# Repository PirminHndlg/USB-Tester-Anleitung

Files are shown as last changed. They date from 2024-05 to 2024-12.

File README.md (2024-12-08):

<h1>Anleitung zum USB Tester Löt Kit</h1>

<div class="img-container">
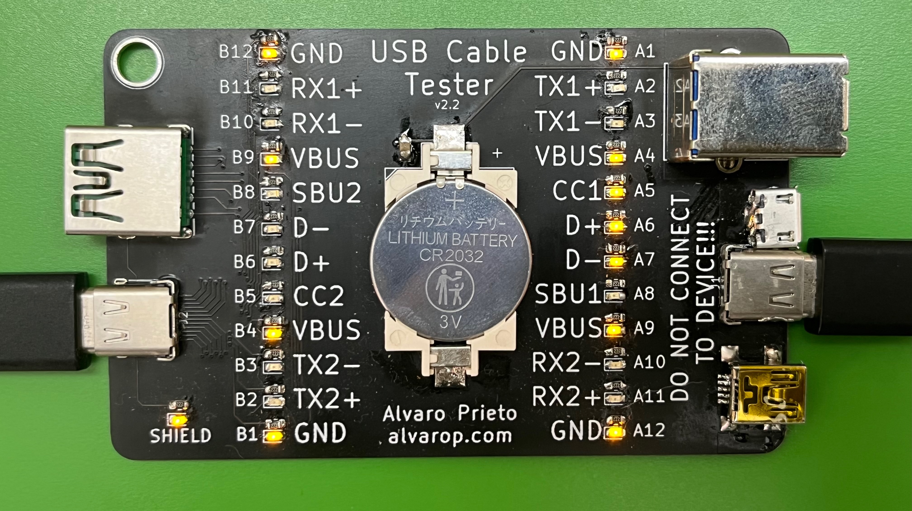
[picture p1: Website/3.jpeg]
    
</div>

<h4>Enthaltene Komponenten</h4>
<ul>
    <li>1x pcb</li>
    <li>2x USB Typ-C Buchse (teilweise schon an pcb angelötet)</li>
    <li>1x USB Typ-A 3.0 Buchse</li>
    <li>1x Micro USB Typ-B Buchse</li>
    <li>1x Mini USB Typ-B Buchse</li>
    <li>1x USB Typ-B 3.0 Buchse</li>
    <li>1x Batterie Halterung</li>
    <li>30x Widerstand 2.2kΩ (25 + 5 Reserve)</li>
    <li>30x LEDs gelb (25 + 5 Reserve)</li>
    <li>1x Kondensator 10μF</li>
</ul>

<div class="img-container">
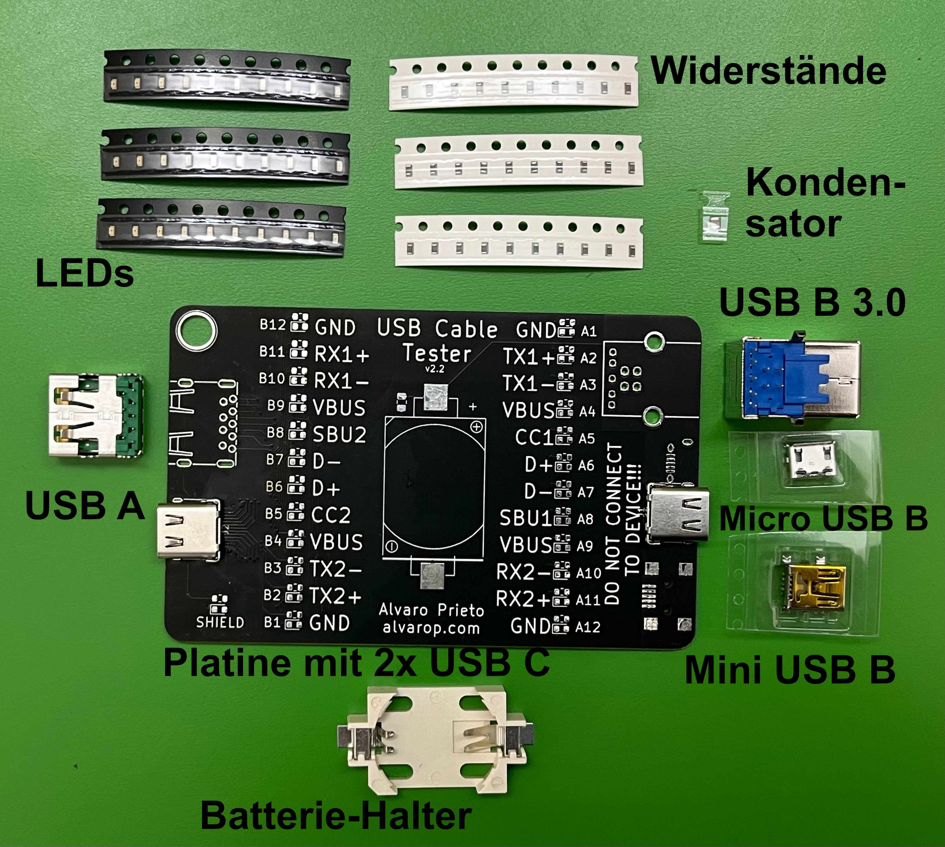
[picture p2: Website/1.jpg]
Komponentenübersicht
    
</div>

<p style="background-color: green; padding: 10px"><strong>Hinweis:</strong> Bei der USB-C Buchse auf der rechten Seite
    kann es sein, dass sich einige Pins untereinander brücken. Das ist kein Problem! Die Kontakte auf dem pcb sind
    sowieso mit einer VCC-Plane verbunden. Auf der linken Seite darf es aber nicht sein!</p>

<h4>Anleitung</h4>
<ol>
    <li>
        Löte die Widerstände und die LEDs auf die Platine, die oberen Kontakte sind für die Widerstände und die
        unteren für die LEDs
        <p style="background-color: red; padding: 10px"><strong>Wichtig:</strong> die LEDs haben eine Ausrichtung!</p>
        <div class="Website/img-container">
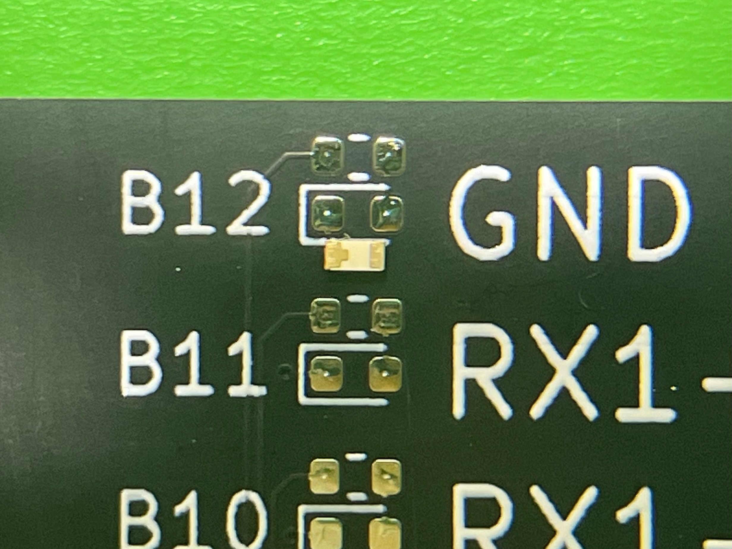
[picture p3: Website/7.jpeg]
Close-Up auf LED-Rückseite
            
        </div>
        Auf der Rückseite der LED sieht man eine Markierung für die Kontakte. Der Kontakt mit dem Kreuz ist der Minuspol
        und muss an den linken Kontakt der Platine mit der vollständigen Umrandung gelötet werden.
        <div class="Website/img-container">
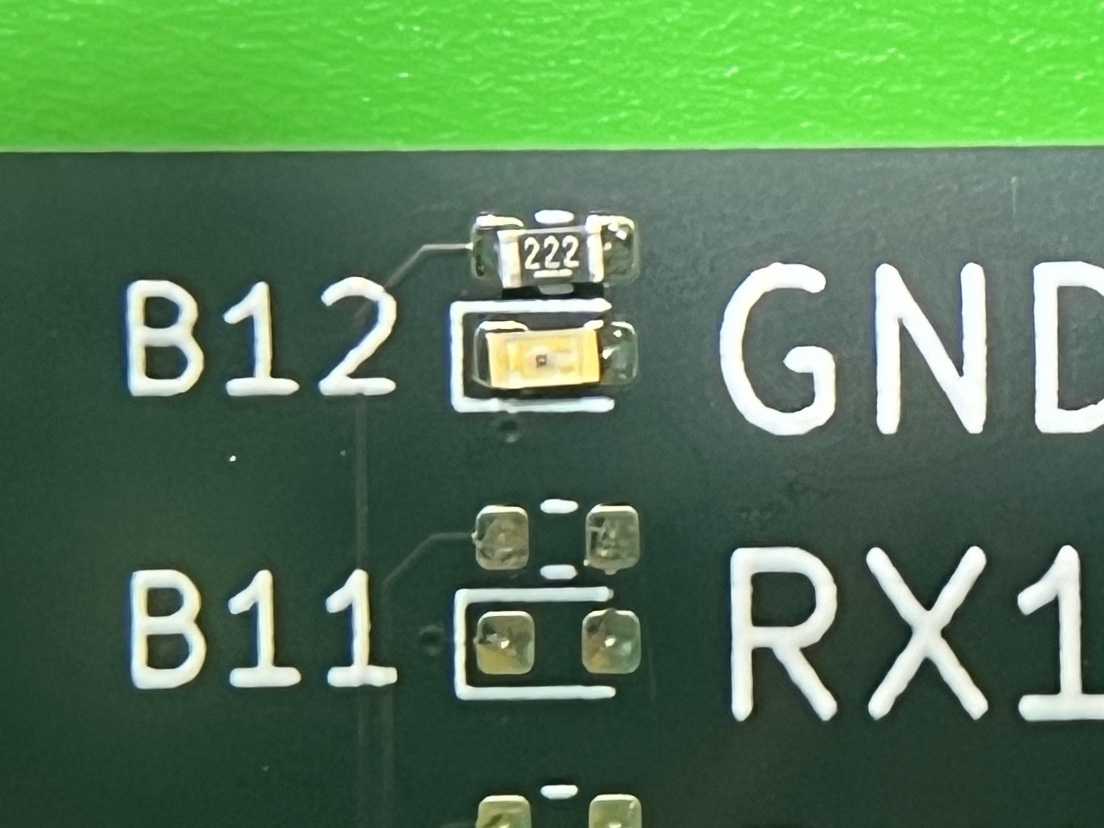
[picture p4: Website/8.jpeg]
Close-Up auf LED und Widerstand
            
        </div>
        Auf der Vorderseite ist die Unterscheidung der beiden Kontakte der LEDs leider nur schwer zu erkennen, aber der
        Pluspol hat zwei kleine Streifen und der Minuspol nur einen.
        <br><br>
        12 LEDs + Widerstände sind für die linke Seite der Platine und 12 für die rechte Seite bestimmt. Das letze Paar
        kommt unten in die linke Ecke der Platine bei der Aufschrift "SHIELD".
    </li>
    <li>
        Löte die Buchsen auf die Platine. Anordnung siehe Bild. Für die Stecker auf der rechten Seite spielt es
        keine Rolle, ob einzelne Kontakte sich untereinander berühren und einen Kurzschluss bilden.
        <div class="img-container">
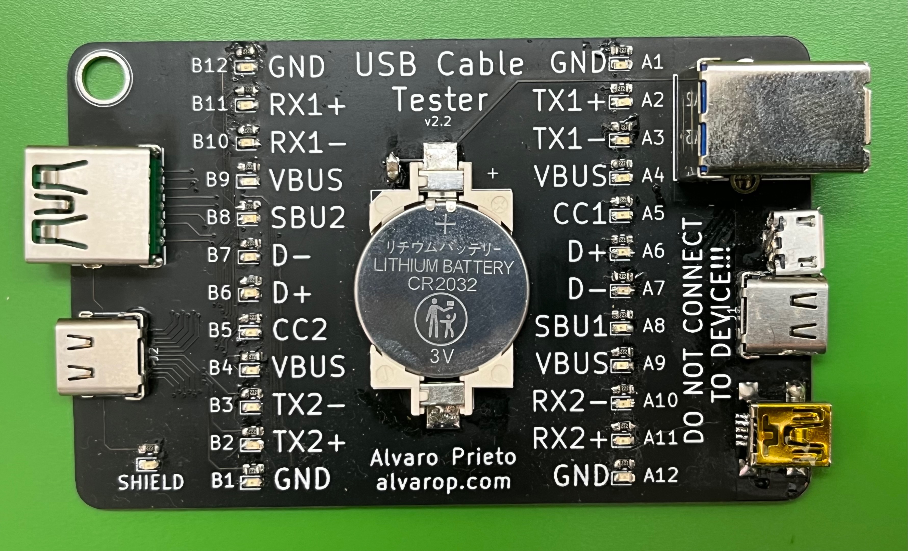
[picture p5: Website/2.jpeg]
Bild von Vorderseite
            
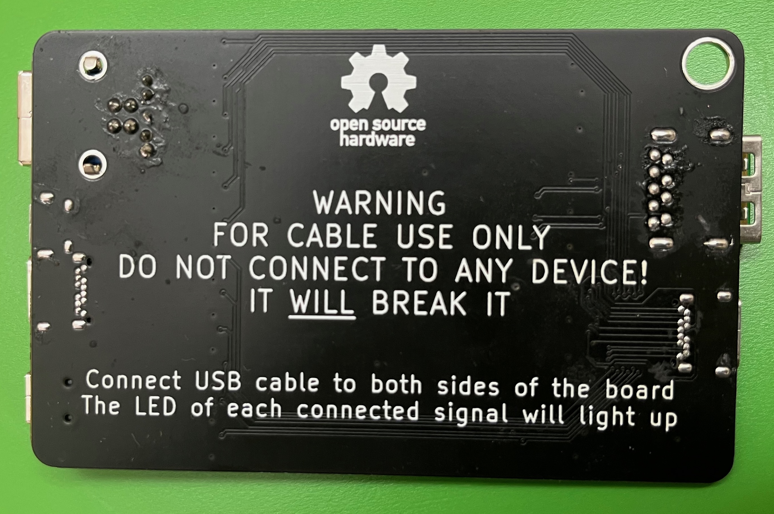
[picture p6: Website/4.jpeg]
Bild von Rückseite
            
        </div>
        Falls die USB-C Buchsen noch nicht angelötet sind, ist das der schwierigste Teil. Ich war am erfolgreichsten,
        indem ich die mit Reflow-Löten angelötet habe.
        <p style="background-color: orange; padding: 10px"><strong>Hinweis:</strong> Bei der Micro-USB-B-Buche habe ich einen kleinen Fehler beim pcb gemacht. Diese muss sich das eine Bein mit einer USB-C-Buchse teilen. Gequetscht sollte aber alles nebeneinander passen.</p>
    </li>
    <li>
        Löte den Kondensator an die richtige Stelle neben dem Pluspol der Batterie. Die Ausrichtung spielt keine Rolle.
        <div class="img-container">
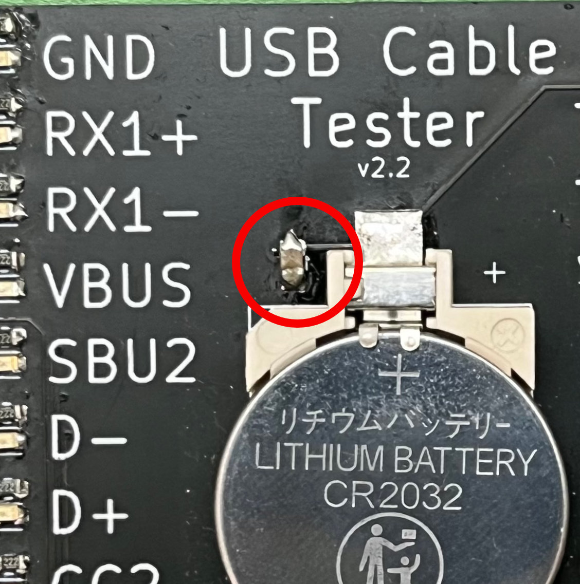
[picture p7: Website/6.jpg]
Close-Up auf Kondensator
            
        </div>
    </li>
    <li>
        Löte die Batterie-Halterung an. Achte auf die richtige Polung! Es gibt eine kleine Markierung an der Ecke der
        Halterung für den Plus- und Minuspol.
    </li>
    <li>
        Und fertig ist dein USB Tester! Viel Spass beim Testen von USB-Kabeln!
    </li>
</ol>

<h3 style="background-color: red; text-align: center; padding: 10px; border-radius: 10px">Wie es auch überall steht, ist es wichtig, dass man
    den Tester <strong>nicht</strong> an ein Gerät anschließt,
    sondern nur Kabel!</h3>

<div class="img-container">
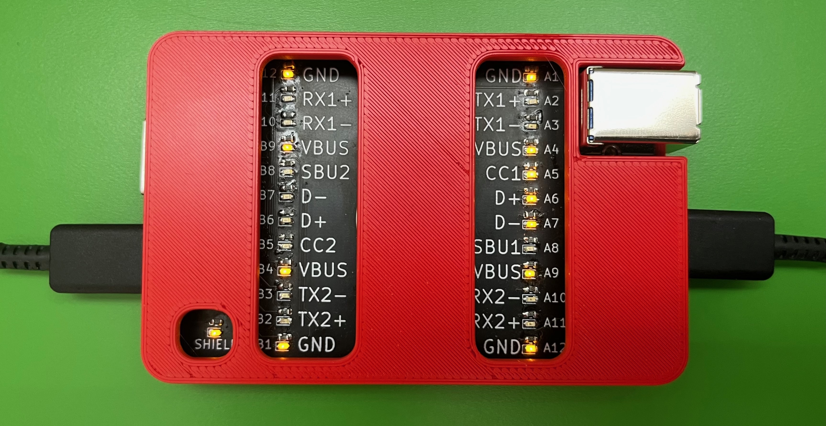
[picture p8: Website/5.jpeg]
Bild von fertigem Tester
    
</div>

<h4>Weitere Links</h4>

<p><a href="https://github.com/PirminHndlg/USB-Tester-Anleitung/tree/main/Case">Hier</a> gibt eine 3D-Druck-Vorlage für
    ein kleines, einfaches Case.</p>

<p><a href="https://github.com/PirminHndlg/USB-Tester-Anleitung/tree/main/pcb">Hier</a> kann man das KiCad-Projekt zum
    pcb finden. Ich habe das <a href="https://github.com/alvarop/usb_c_cable_tester">Original von alvarop</a> etwas
    angepasst, da einzelne Teile nicht mehr verfügbar waren. Eine aktuelle Liste gibt es <a
            href="https://github.com/PirminHndlg/USB-Tester-Anleitung/blob/main/pcb/LCSC%20Exported%20May%2030%202024.csv">hier</a>
</p>

<h4>Erklärung zur Pin-Belegung</h4>

<div class="table-container">
    <table>
        <tr>
            <th>Charge only</th>
            <td>GND</td>
            <td>VBUS</td>
        </tr>
        <tr>
            <th>USB 2.0</th>
            <td>GND</td>
            <td>VBUS</td>
            <td>D-</td>
            <td>D+</td>
        </tr>
        <tr>
            <th>USB 3.0</th>
            <td>GND</td>
            <td>VBUS</td>
            <td>D-</td>
            <td>D+</td>
            <td>RX-</td>
            <td>RX+</td>
            <td>TX-</td>
            <td>TX+</td>
        </tr>
    </table>
</div>
<p>Bei USB-C als Host (Buchse auf linker Seite) und Client (Buchse auf rechter Seite) leuchten beide Seiten, da dann
    sowohl die A als auch die B Pins verbunden sind. Außerdem sollte mind. ein CC-Pin verbunden sein</p>

<div class="img-container">
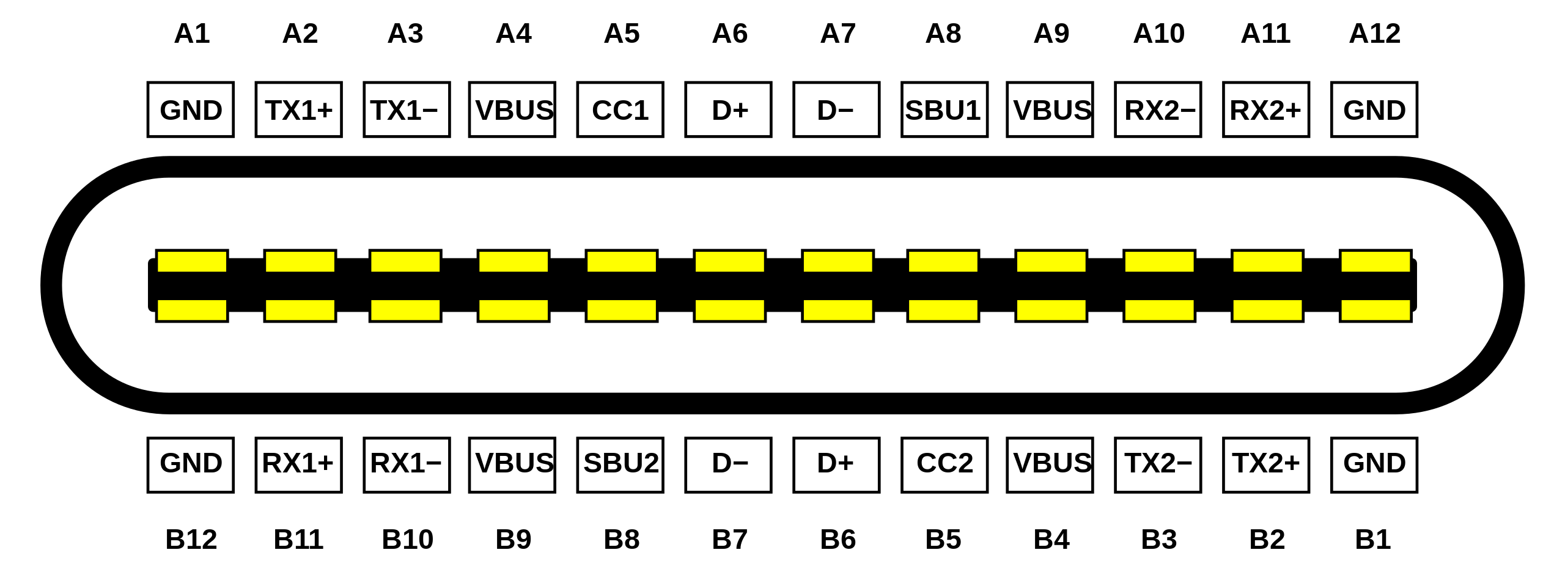
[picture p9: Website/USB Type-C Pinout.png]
Pinbelegung von USB C
    
</div>

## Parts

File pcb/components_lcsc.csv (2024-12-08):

LCSC Part Number | Manufacture Part Number | Manufacturer | Customer NO. | Package | Description | RoHS | Order Qty. | Min\Mult Order Qty. | Unit Price($) | Order Price($)
C72038 | 19-213/Y2C-CQ2R2L/3T(CY) | Everlight Elec |  | 0603 | 20mA Colorless Transparent Lens -40℃~+85℃ 585.5nm~591.5nm Yellow 120° 60mW 0603 LED Indication - Discrete ROHS | YES | 1500 | 30\30 | 0.0147 | 22.05
C70377 | CR2032-BS-6-1 | Q&J |  | SMD | Battery holder CR2032 SMD Button And Strip Battery Connector ROHS | YES | 50 | 5\5 | 0.125 | 6.25
C381137 | U231-091N-3GRC10 | XKB Connection |  | Plugin | 3A 1 9P Mother -40℃~+85℃ Type-A Plugin USB Connectors ROHS | YES | 50 | 1\1 | 0.3194 | 15.97
C2681563 | MINI 5PTP | SHOU HAN |  | SMD | 1A 1 Horizontal attachment 5P Mother -30℃~+80℃ SMD USB Connectors ROHS | YES | 50 | 10\10 | 0.0576 | 2.88
C2895032 | USB-306BWD-ARW | XUNPU |  | Plugin | USB 3.0 1.8A 1 Bend-in 9P Mother -55℃~+85℃ Type-B Plugin USB Connectors ROHS | YES | 50 | 1\1 | 0.3618 | 18.09
C15850 | CL21A106KAYNNNE | Samsung Electro-Mechanics |  | 0805 | 25V 10uF X5R ±10% 0805 Multilayer Ceramic Capacitors MLCC - SMD/SMT ROHS | YES | 50 | 50\50 | 0.0092 | 0.46
C4190 | 0603WAF2201T5E | UNI-ROYAL(Uniroyal Elec) |  | 0603 | 100mW Thick Film Resistors 75V ±100ppm/℃ ±1% 2.2kΩ 0603 Chip Resistor - Surface Mount ROHS | YES | 1500 | 100\100 | 0.0007 | 1.05
C456013 | TYPE-C 24P QCHT | SHOU HAN |  | SMD | USB 3.1 3A 1 Horizontal attachment 24P Mother -40℃~+85℃ Type-C SMD USB Connectors ROHS | YES | 100 | 1\1 | 0.2745 | 27.45
C10418 | 920-E52A2021S10100 | Jing Extension of the Electronic Co. |  | SMD | 1A USB 2.0 1 5P Mother Micro-B SMD USB Connectors ROHS | YES | 50 | 5\5 | 0.0517 | 2.59

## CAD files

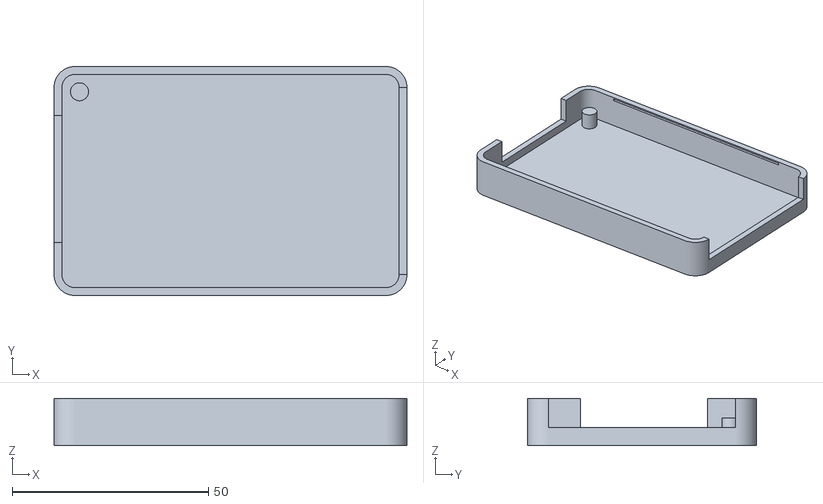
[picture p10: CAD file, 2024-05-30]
Case/USB C Cable Tester Parts Body.stl
90.0 x 58.4 x 12.0

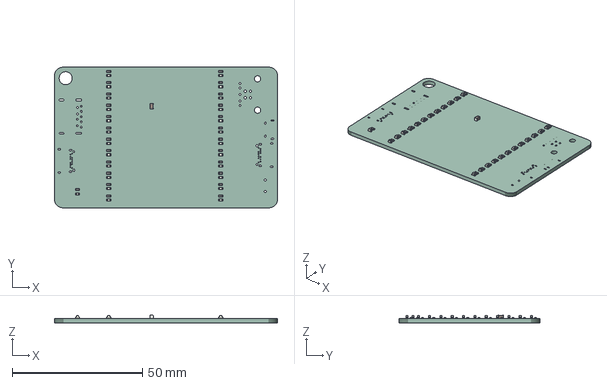
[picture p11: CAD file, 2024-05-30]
pcb/kicad/usb_c_cable_tester.step
85.6 x 54.0 x 2.88 mm
usb_c_cable_tester PCB

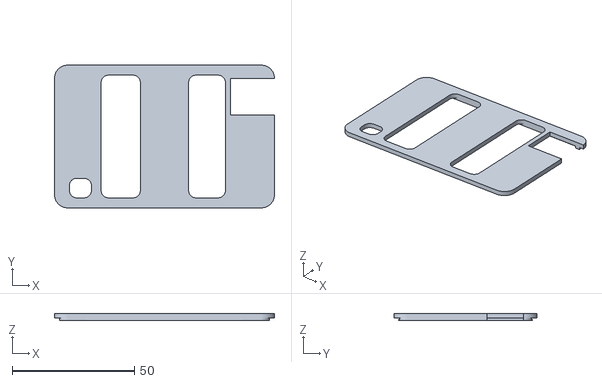
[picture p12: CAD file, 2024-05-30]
Case/USB C Cable Tester Parts Lid.stl
90.0 x 58.4 x 3.00

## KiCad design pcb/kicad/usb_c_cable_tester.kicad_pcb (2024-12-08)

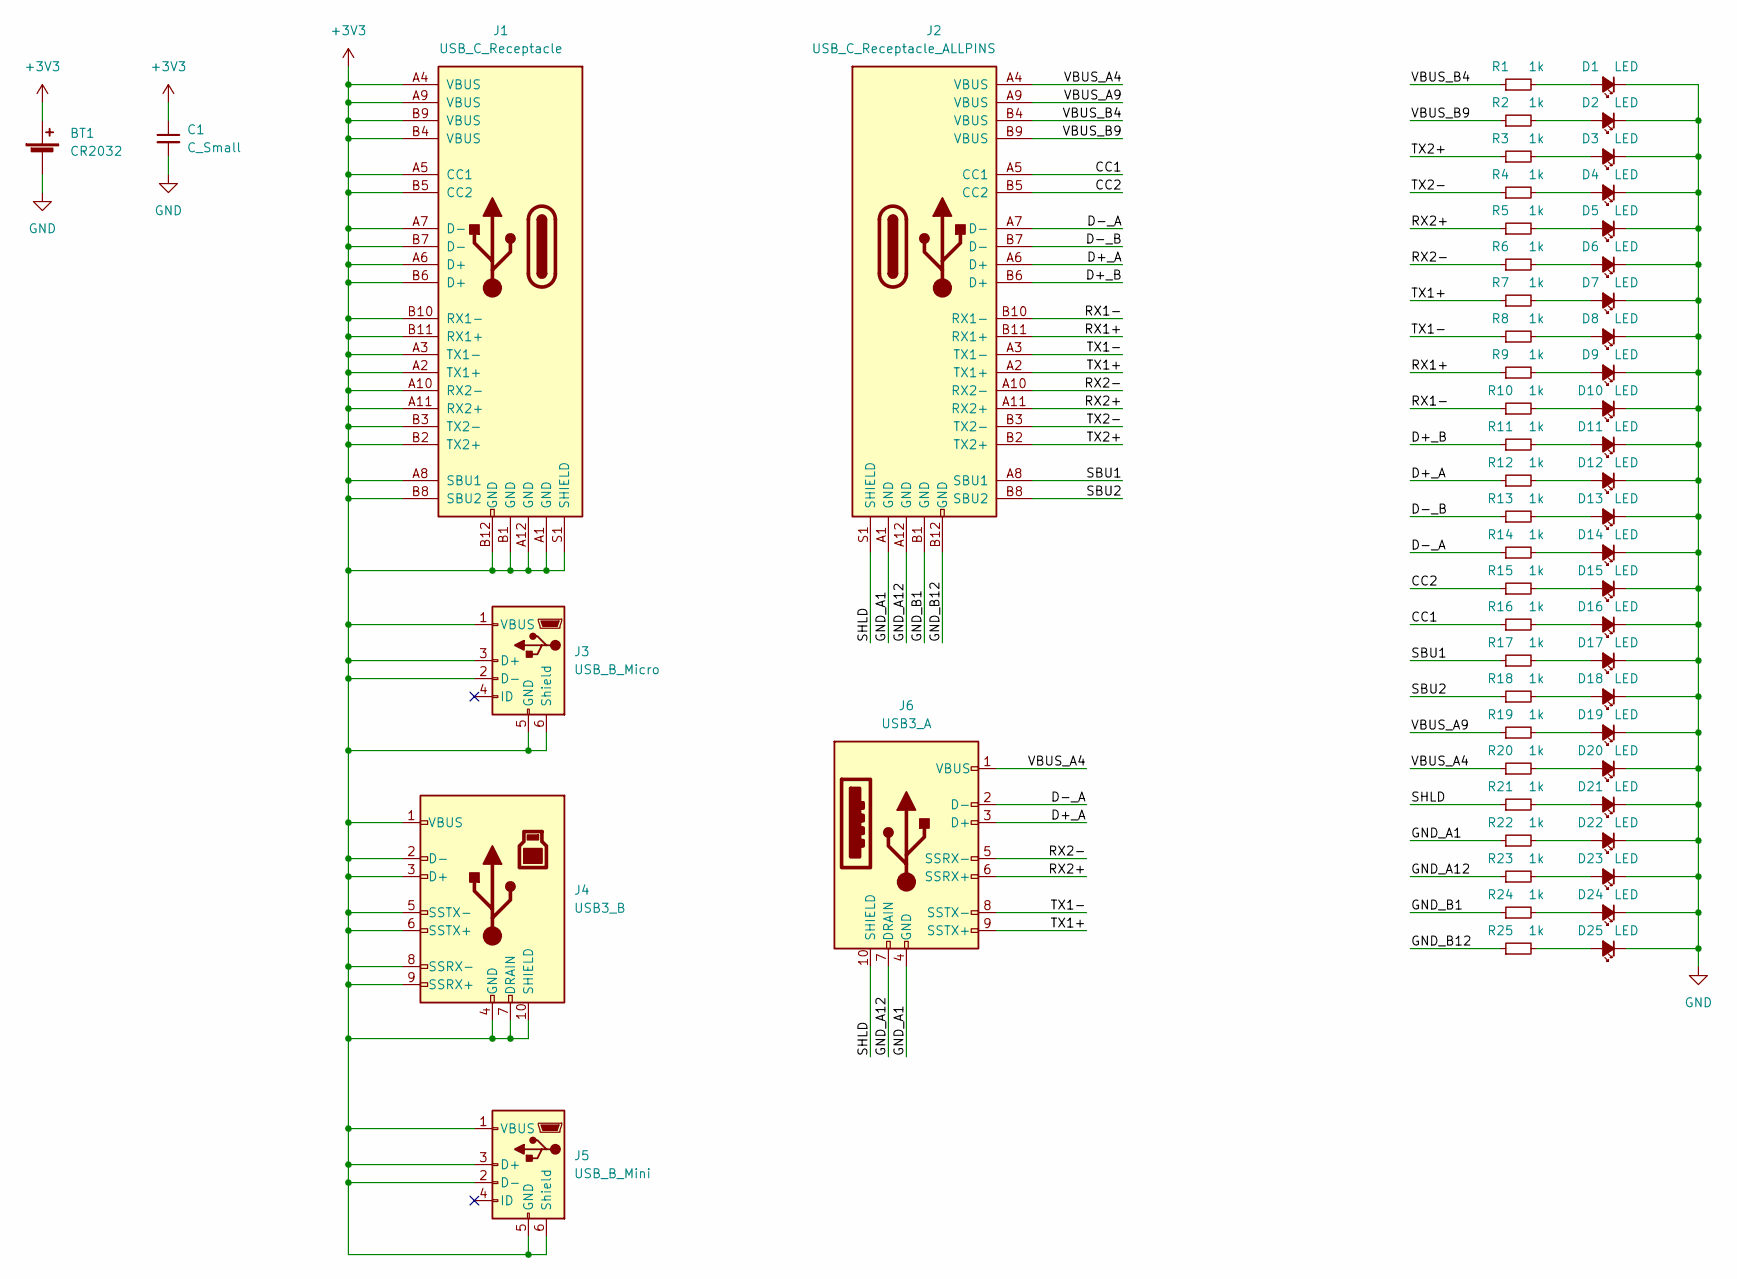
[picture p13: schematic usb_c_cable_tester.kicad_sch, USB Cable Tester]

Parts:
BT1: CR2032; BAT-TH_CR2032-BS-6-1; LCSC C70377
C1: C_Small; C_0805_2012Metric; LCSC C15850
D1, D2, D3, D4, D5, D6, D7, D8, D9, D10, D11, D12, D13, D14, D15, D16, D17, D18, D19, D20, D21, D22, D23, D24, D25: LED; LED_0603_1608Metric; LCSC C72038
J1: USB_C_Receptacle; USB_C; LCSC C456013
J2: USB_C_Receptacle_ALLPINS; USB_C; LCSC C456013
J3: USB_B_Micro; MICRO-USB-SMD_10118194-0001LF; LCSC C132563
J4: USB3_B; USB-B-TH_XUNPU_USB-306BWD-ARW; LCSC C2895032
J5: USB_B_Mini; MINI-USB-SMD_MINI-5PTP; LCSC C2681563
J6: USB3_A; USB-A-TH_U231-091N-5; LCSC C381137
R1, R2, R3, R4, R5, R6, R7, R8, R9, R10, R11, R12, R13, R14, R15, R16, R17, R18, R19, R20, R21, R22, R23, R24, R25: 1k; R_0603_1608Metric; LCSC C4190

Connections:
+3V3: BT1.1 (+), C1.1, J1.A1 (GND), J1.A2 (TX1+), J1.A3 (TX1-), J1.A4 (VBUS), J1.A5 (CC1), J1.A6 (D+), J1.A7 (D-), J1.A8 (SBU1), J1.A9 (VBUS), J1.A10 (RX2-), J1.A11 (RX2+), J1.A12 (GND), J1.B1 (GND), J1.B2 (TX2+), J1.B3 (TX2-), J1.B4 (VBUS), J1.B5 (CC2), J1.B6 (D+), J1.B7 (D-), J1.B8 (SBU2), J1.B9 (VBUS), J1.B10 (RX1-), J1.B11 (RX1+), J1.B12 (GND), J1.S1 (SHIELD), J3.1 (VBUS), J3.2 (D-), J3.3 (D+), J3.5 (GND), J3.6 (Shield), J4.1 (VBUS), J4.2 (D-), J4.3 (D+), J4.4 (GND), J4.5 (SSTX-), J4.6 (SSTX+), J4.7 (DRAIN), J4.8 (SSRX-), J4.9 (SSRX+), J4.10 (SHIELD), J5.1 (VBUS), J5.2 (D-), J5.3 (D+), J5.5 (GND), J5.6 (Shield)
/CC1: J2.A5 (CC1), R16.1
/CC2: J2.B5 (CC2), R15.1
/D+_A: J2.A6 (D+), J6.3 (D+), R12.1
/D+_B: J2.B6 (D+), R11.1
/D-_A: J2.A7 (D-), J6.2 (D-), R14.1
/D-_B: J2.B7 (D-), R13.1
/GND_A1: J2.A1 (GND), J6.4 (GND), R22.1
/GND_A12: J2.A12 (GND), J6.7 (DRAIN), R23.1
/GND_B1: J2.B1 (GND), R24.1
/GND_B12: J2.B12 (GND), R25.1
/RX1+: J2.B11 (RX1+), R9.1
/RX1-: J2.B10 (RX1-), R10.1
/RX2+: J2.A11 (RX2+), J6.6 (SSRX+), R5.1
/RX2-: J2.A10 (RX2-), J6.5 (SSRX-), R6.1
/SBU1: J2.A8 (SBU1), R17.1
/SBU2: J2.B8 (SBU2), R18.1
/SHLD: J2.S1 (SHIELD), J6.10 (SHIELD), R21.1
/TX1+: J2.A2 (TX1+), J6.9 (SSTX+), R7.1
/TX1-: J2.A3 (TX1-), J6.8 (SSTX-), R8.1
/TX2+: J2.B2 (TX2+), R3.1
/TX2-: J2.B3 (TX2-), R4.1
/VBUS_A4: J2.A4 (VBUS), J6.1 (VBUS), R20.1
/VBUS_A9: J2.A9 (VBUS), R19.1
/VBUS_B4: J2.B4 (VBUS), R1.1
/VBUS_B9: J2.B9 (VBUS), R2.1
GND: BT1.2 (-), C1.2, D1.1 (K), D2.1 (K), D3.1 (K), D4.1 (K), D5.1 (K), D6.1 (K), D7.1 (K), D8.1 (K), D9.1 (K), D10.1 (K), D11.1 (K), D12.1 (K), D13.1 (K), D14.1 (K), D15.1 (K), D16.1 (K), D17.1 (K), D18.1 (K), D19.1 (K), D20.1 (K), D21.1 (K), D22.1 (K), D23.1 (K), D24.1 (K), D25.1 (K)
unnamed: D1.2 (A), R1.2
unnamed: D2.2 (A), R2.2
unnamed: D3.2 (A), R3.2
unnamed: D4.2 (A), R4.2
unnamed: D5.2 (A), R5.2
unnamed: D6.2 (A), R6.2
unnamed: D7.2 (A), R7.2
unnamed: D8.2 (A), R8.2
unnamed: D9.2 (A), R9.2
unnamed: D10.2 (A), R10.2
unnamed: D11.2 (A), R11.2
unnamed: D12.2 (A), R12.2
unnamed: D13.2 (A), R13.2
unnamed: D14.2 (A), R14.2
unnamed: D15.2 (A), R15.2
unnamed: D16.2 (A), R16.2
unnamed: D17.2 (A), R17.2
unnamed: D18.2 (A), R18.2
unnamed: D19.2 (A), R19.2
unnamed: D20.2 (A), R20.2
unnamed: D21.2 (A), R21.2
unnamed: D22.2 (A), R22.2
unnamed: D23.2 (A), R23.2
unnamed: D24.2 (A), R24.2
unnamed: D25.2 (A), R25.2

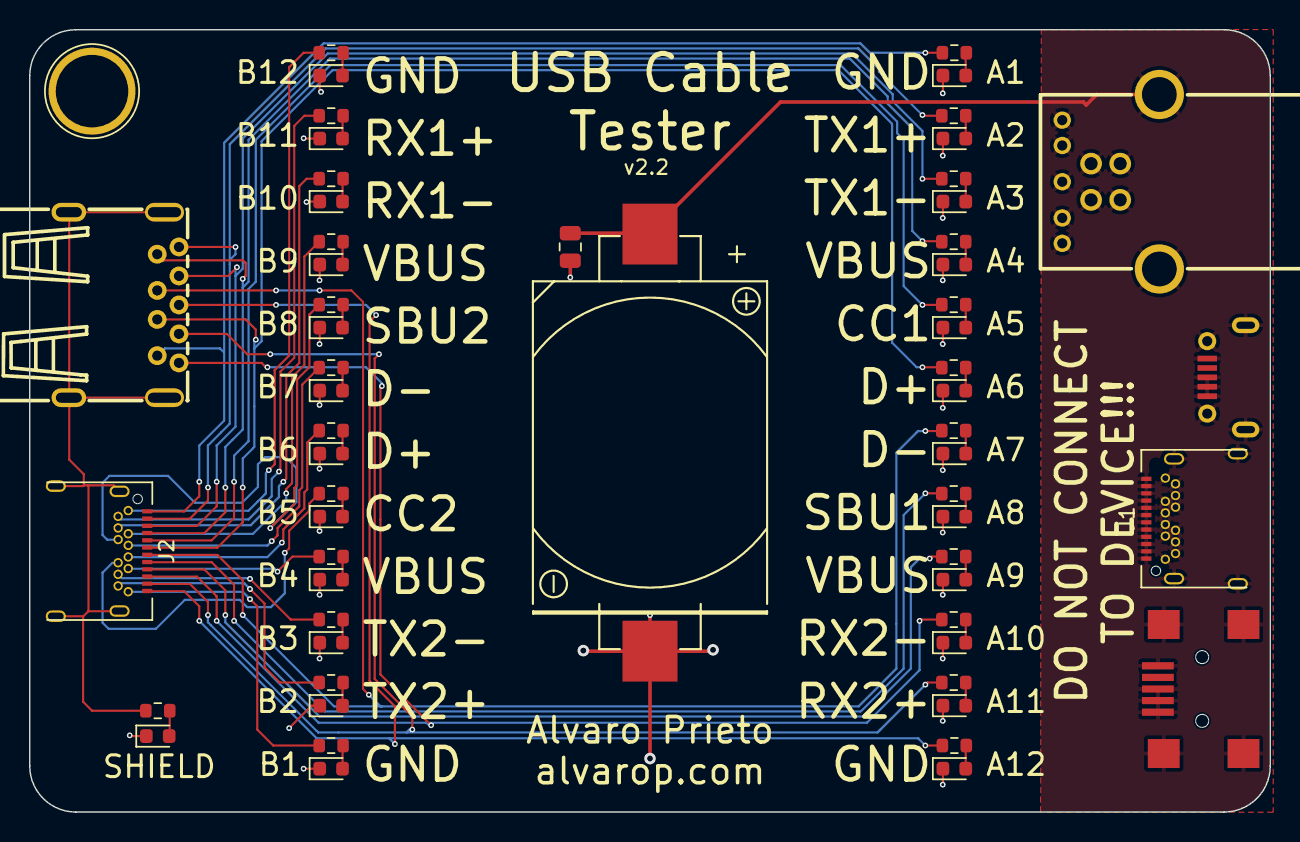
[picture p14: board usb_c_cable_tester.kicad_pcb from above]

Board: 2 copper layers, 85.6 x 54.0 mm, 58 parts (0 on the bottom side), 52 nets.

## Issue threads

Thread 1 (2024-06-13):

Micro USB bei der GPN Version zu nahe am USB-C Port

dasrecht, 2024-06-13:
Hi P0k :wave:

Danke für das zusammenstellen des Kits an der GPN :) Funktioniert einwandfrei

Einzig gemerkt habe ich das der Micro-USB sehr nahe am USB-C ist. Evtl war da ein bisschen ungenau gearbeitet worden bei der PCB Fabrikation. Dachte ich melde das noch; eventuell weisst du das aber schon.

Gruss /dasrecht

p.s. danke für die Ersatzteile (hab einige gebraucht :joy: )

PirminHndlg, 2024-06-14:
Das freut mich zu hören, dass alles funktioniert!

Genau das mit der Micro-USB-Buchse war ein kleiner Fehler von mir. Die habe ich falsch hingesetzt (in den aktuellen gbr-Files ist es richtig). Aber irgendwie klappt es die dazuzuquetschen.

dasrecht, 2024-06-14:
Hah okay :D dachte schon ich hätte irgendwo was schief angelötet :) Funktioniert alles wie geplant :D

Closed 2024-06-14.

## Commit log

2024-05-30 Case files
    [USB C Cable Tester Parts 6.stl, USB C Cable Tester Parts Body.stl, USB C Cable Tester Parts Lid.stl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]
2024-05-30 added pcb design
    [usb_c_cable_tester-B_Cu.gbr, usb_c_cable_tester-B_Mask.gbr, usb_c_cable_tester-B_Paste.gbr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]
2024-05-30 csv of componentes
    [LCSC Exported May 30 2024.csv]
2024-05-30 renamed files
    [USB C Cable Tester Parts 6.stl, USB C Cable Tester Parts.stl]
2024-06-01 some more infos for gnd plane
2024-06-01 gnd -> vcc
2024-12-08 changes (and a bit chaos)
    [LCSC Exportiert Mai 30 2024.csv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]
2024-12-08 moved files to kicad folder
    [usb_c_cable_tester-B_Cu.gbr, usb_c_cable_tester-B_Mask.gbr, usb_c_cable_tester-B_Paste.gbr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]
2024-12-08 removed not needed files
    [usb_c_cable_tester-B_Cu.gbr, usb_c_cable_tester-B_Mask.gbr, usb_c_cable_tester-B_Paste.gbr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]
2024-12-08 chaos and added components file for ordering at lcsc
    [LCSC Exportiert Mai 30 2024.csv, components_lcsc.csv]
2025-10-27 Add files for pcb production and flyer file
